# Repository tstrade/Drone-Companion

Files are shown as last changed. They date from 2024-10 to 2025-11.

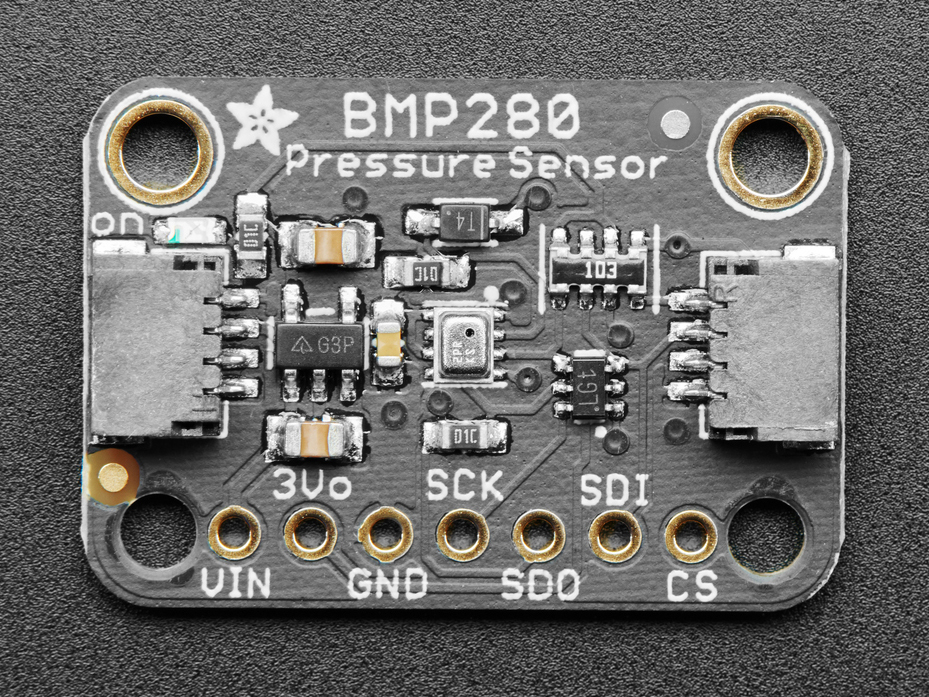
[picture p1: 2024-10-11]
Hardware/Pinouts/BMP280_Pinouts.jpg

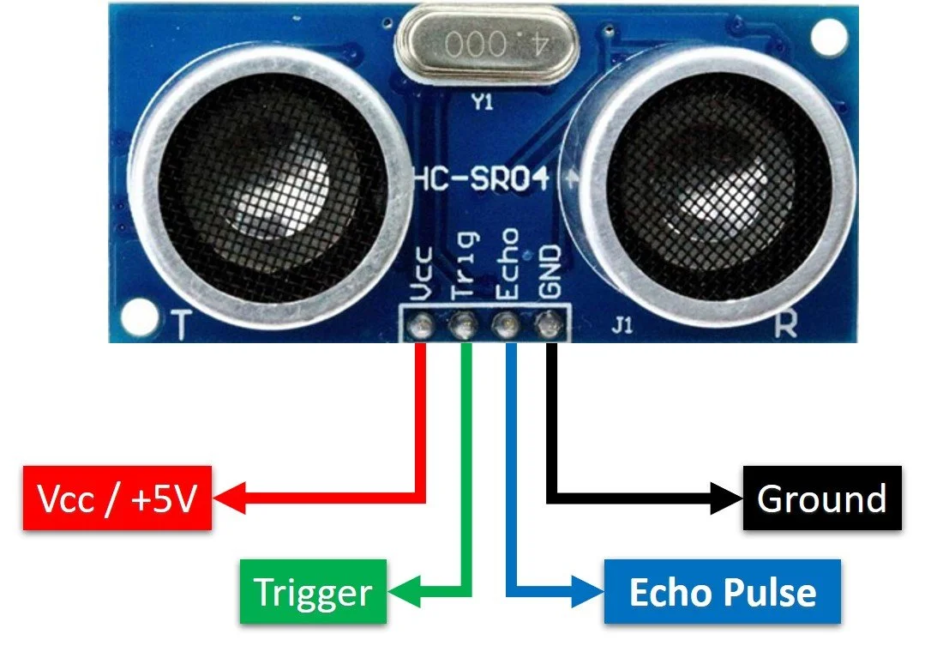
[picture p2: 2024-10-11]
Hardware/Pinouts/HC-SR04-Pinout.png

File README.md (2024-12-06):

# Drone-Companion
We will implement an assistive technology drone that will fly at a specific height above the user and detect, avoid, and alert when there are any obstacles. Obstacle can be constituted as anything that is large and can be ran into when walking around outside or in a building (i.e. walls, poles, tables, chairs, other people).  

The drone will follow the user while they walk around, maintaining that same distance every time the user moves while also monitoring the environment around the user to detect and avoid any other obstacles. It will specifically alert the user when there is an object in front of them that is getting closer and within some fixed proximity. 

***
# Repository Tour
- *Software*
    - Test code
    - Wokwi Simulations
    - Libraries downloaded to be used for the Drone Companion

- *Hardware*
    - Pinouts
    - Component markdown detailing inputs, outputs, and other specifications (as well as links to the manufacturers)
    - Datasheets
    - Designs used to 3D print the frame
    - Wokwi link to full wiring layout
 
- *Final Product*
    - Full prototype code / sketch
    - Full wiring layout
    - README.md detailing setup, use, and other important notes
 
- *Other*
    - Phase 1 Document: Project Proposal
    - Phase 2 Document: Prototype Progress Update

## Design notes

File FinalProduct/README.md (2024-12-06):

# Drone Companion - Prototype Setup and Functionality
***
## Setup:
1. Load Drone-Companion/FinalProduct/MasterCode/MasterCode.ino into the Arduino IDE
2. Connect Mini-B USB cable from laptop to Arduino Nano USB port and upload the code (nonstandard missing libraries can be found in the Drone-Companion repository)
3. Place the drone on a flat spot (ground, chair, table) and then upload the sketch
4. When the serial monitor instructs you to do so, plug the LiPo battery into the PDB
5. The motors will make a few short beeps and then one long beep to confirm the motors have been armed, then press the IR remote's ON button

***
## How to Use the Drone Companion:
- After the Drone Compion has been setup, it will initiate its takeoff protocol
  - To complete the takeoff protocol, the Drone Companion must be raised to a height 1 meter (approx. 3 feet) above its starting position
 
- After the takeoff protocol, the Drone Companion will assume its hover protocol
    - *Using the IR Remote*
        - The code received by the sensor starts from 0 (top left button), followed by 1, 2, 3; the next row will start on code 4, and so on
        - Using the codes:
            - **Code 1**: Hover protocol
            - **Code 2**: Takeoff protocol
            - **Code 3**: Landing protocol
            - **Other Codes**: Follow protocol
  
    - *Protocols*
        1. **Hover**: maintain a stable / constant height
        2. **Takeoff**: increase motor speed until 1 meter higher than the starting position
        3. **Land**: reduce drone speed over ~30 second period and then stop motors completely
        4. **Follow**: maintain distance from user by moving forwards or backwards
         
    - *Special Behavior*
        - **Hover** will not respond to user distance or obstacle proxomity
        - **Takeoff** can only occur when the drone is landed. If the takeoff protocol is activated while the drone is airborn, it will skip the takeoff sequence and default to the hover protocol
        - **Land** can only occur when the drone is airborn. If the landing protocol is activated while the drone is grounded, nothing will happen.
        - **Follow** will trigger the alarm if an obstacle comes too close to the drone and will only silence when the obstalce has moved away

***
## Notes:
- *LiPo Battery Life* - A fully charged 2200 mAh will allow the drone to run for approximately 6 to 10 minutes continuously before it needs to be recharged.
  
- *Calibration Sequences* - The Drone Companion should not be moved during setup, as it is taking time to calibrate the gyroscope. Additionally, the battery should not be plugged in nor the IR remote used sooner than indicated. This could cause an improper setup and remove any guarantee that the Drone Companion will function as expected.
    - You can find our version of a motor / ESC calibration sequence in "Drone-Companion/Software/Test Code"
 
- *Project Replication* - If you are building your own version, make sure to calibrate the motors to their specified minimum and maximum throttle in a sketch separate from the rest of the hardware. This usually only needs to happen once, but improper calibration or power malfunctions could reset this process. Make sure to follow the manufacturer's specifications. Additionally, PID control constants and complementary filters are NOT universal: these parameters are sensitive and should be tested extensively with the hardware you choose to use.
    - Research the hardware you are using. Understanding the units of the inputs and outputs is vital to proper testing. Additionally, some components may interfere with one another. For example, in this implementation, the IR sensor and buzzer use the same clock timer from the Arduino Nano - such a resource must be mutually exclusive
  
- *Testing Environment* - To avoid broken parts and/or injury, conduct initial testing without propellors. Use the Serial Monitor and visual/auditory queues to debug the motors's reaction to stimulus. When appropriate, choose a safe space to tie at least two of the motor props to heavy objects. It should be high enough off the ground that it will not crash in the event of an error, and tied in such a way that it cannot cut itself loose. Motors are powerful - make sure whatever you secure the drone with will not break from the force created by the drone. Finally, motors rotate over a hundred times per second, so propellors are essentially mini blades if you are not careful. Wear protective clothing and glasses while testing your drone.
 
***
## Final Remarks:
  In the timespan of ~3 months (as of Dec. 6, 2024), this drone has gone from an idea to a functional prototype. This prototype has not yet achieved full flight, due to complications such as the ones we have warned against above, as well as the limited resource that is time. Moving forward, there are two more major phases planned for the Drone Companion:
    - Phase 4 will include a remastering of the drone - a new frame, reorganized wiring, memory optimization, parameter refinement, and sensible testing. The goal of this phase is to have the drone successfully complete its takeoff, hover, and landing protocols.
    - Phase 5 will result in the final product, in which the drone will be able to enter its follow protocol and operate in a smooth, controlled manner.

  If you are seeking to build your own drone using an Arduino, or another microcontroller, it is important to not be discouraged. Integrating sensitive hardware requires careful and extensive testing, and lots (and we mean a lot) of failure. Many online forums, such as the Arduino Forum and Reddit, discourage programmers new to microcontrollers to not bother with a drone. Of course, there are also many useful tips out there on the internet - you just have to look around hard enough to find useful information that applies to you. Hopefully, this project will stand as a testimate to the power of determination and the pursuit of knowledge. 

Sincerely, 
Two undergraduates with a vision

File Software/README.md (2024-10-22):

This folder contains all necessary code, as well as psuedocode, pertaining to the operation
of the Drone Companion. Coding will be done in C and interfaced with an Arduino Nano. 

In the section below, each simulation serves as a basic example of how each of the hardware components will interact with our software individually and
how the software will communicate I/O data between different combinations of components. 

## Wokwi Simulations
### Individual Component Tests
- [Radar Sensor - HC-SR04](https://wokwi.com/projects/412025867077022721)
- [Gyroscope & Accelerometer - MPU6050](https://wokwi.com/projects/412048270927496193)
- [Altitude Sensor - BMP280](https://wokwi.com/projects/412088879688243201)
  
***
### Paired Component Tests
- [Radar Sensors, Accelerometer, Altitude Sensor, Buzzer](https://wokwi.com/projects/412369553864428545)

***

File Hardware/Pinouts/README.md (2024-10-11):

This directory contains Pinout Diagrams for all hardware components in the Drone Companion design.

Additional / More Descriptive info for the BMP280 pins are found [here](https://learn.adafruit.com/adafruit-bmp280-barometric-pressure-plus-temperature-sensor-breakout/pinouts)

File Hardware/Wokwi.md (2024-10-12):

[Here](https://wokwi.com/projects/411396309418092545) is the share link to the Drone Companion's hardware connections.

Current Items:
1. Arduino Nano
2. Radar sensor x2 (HC-SR04)
3. Altitude sensor (BMP280 - custom chipset)
4. 6-Axis Accelerometer & Gyro (MPU6050 - not final; stand-in component)
5. IR Receiver
6. Buzzer

Missing Items:
1. ESC x4
2. Brushless Motors x4
3. Power Control Board (possibly not necessary)
4. LiPO Battery (Ideally 45-60 min. flight time)
5. Medium breadboard

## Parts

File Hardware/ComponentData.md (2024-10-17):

# **Ultrasonic Sensor**
## Electric Parameters:

| Working Voltage | DC 5V |
| :---: | :---: |
| Working Current | 15mA |
| Working Frequency | 40Hz |
| Range | 0.03 - 13.12ft |
| Accuracy | 0.01ft|
| Measuring Angle | 15 degrees |
| Trigger Input Signal | 10us TTL Pulse |
| Echo Output Signal | Input TTL level signal and the range in proportion |

[Transistor-Transistor Logic (TTL)](https://meanwellpowersupplies.com/faq/what-is-a-ttl-signal/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,5V%20is%20a%20high%20state.)

- Basic Principles:
  1. Use I/O trigger for at least 10us logic HI
  2. Module automatically sends eigth 40kHz and detects whether there is a pulse signal back
  3. If there is a pulse signal back, through logic HI, time of logic HI I/O duration is from time sending ultrasonic to returning
  4. Appropriate test distance = (logic HI time * 1115ft/s)/2
       - where 1115ft/s is approx. the speed of sound (340m/s) in feet
    
- Wire Connections:
    - 5V supply
    - Trigger Pulse Input
    - Echo Pulse Output
    - 0V ground

The timing diagram and all information listed in this section can be found in the Ultrasonic Ranging Module HC-SR04 datasheet included in this repository. Any additional information may be found in the module's [Github Repository](https://github.com/sparkfun/HC-SR04_UltrasonicSensor)

## Dimensions:
- 45 x 20 x 15 millimeters
- 1.8 x 0.8 x 0.6 inches

## Input Data:
- To trigger, send a 10us TTL pulse to the module
  - TTL logic HI:  ~ 2.7 - 5.0V
  - TTL logic LO: ~ 0.0 - 0.4V
  - Note: This information might vary based on our component's capabilities. The TTL link above, as well as others, tend to be product-specific.
 
- Suggested to use a measurement cycle > 60ms to avoid I/O overlap

## Output Data:
- Sends a TTL pulse "with a range in proportion"
- The distance, in inches, of the object that is within the range/width of the sensor is defined as $$d = \frac{t_{o} - t_{i}}{148}$$

***
# **Altitude Sensor**
## Overview
- Barometric Pressure Accuracy: $\pm 1$ hPa
- Temperature Accuracy: $\pm 1.0^\circ$C
- Altimeter Accuracy: $\pm 1$ meter
- Low Altitude Noise: $0.25$ meters
- ! Can be used with 3.3V or 5V systems thanks to built-in voltage regulator

## Pinouts:
| Pins | Use |
| :---: | :---: |
| Vin | Power pin - use same power as logic level of microcontroller |
| 3Vo | 3.3V output from voltage regulator - can grab up to 100mA |
| GND | Common ground for power and logic |
| --------- | --------------------------------------------------------------------------------- |
| ***SPI*** | ***PROTOCOL PINS*** |
| SCK | SPI Clock Pin - input to chip |
| SDO | Serial Data Out / Microcontoller In Sensor Out pin - data sent from sensor to processor |
| SDI | Serial Data In / Microcontroller Out Sensor In pin - data sent from processor to sensor |
| CS | Chip Slect pin - drop to low to start SPI transaction; input to chip |
| --------- | --------------------------------------------------------------------------------- |
| ***I2C*** | ***PROTOCOL PINS*** |
| SCK (SCL) | I2C Clock Pin - connect to microcontroller's I2C clock line |
| SDI (SDA) | I2C Data Pin - connect to microcontroller's I2C data line |
| SDO | Leave unconnected |
| CS | Leave unconnected |

[BMP280 to Arduino Wiring-by-Protocol](https://learn.adafruit.com/adafruit-bmp280-barometric-pressure-plus-temperature-sensor-breakout/arduino-test)

## Input/Output Data:

Adafruit provides a library for the BMP280 that is available from the Arduino library manager, and can be installed from GitHub [here](https://github.com/adafruit/Adafruit_BMP280_Library/tree/master).

Additionally, the GitHub repository includes a few examples on how to interact with the BMP280 through an Arduino sketch. It is encouraged to review this documentation, but the examples can be summarized as follows: initialize sensor, call for a temperature and/or pressure reading using `getEvent()`, and store or print the value obtained by the sensor. 

What to look into during the coding subphase: 
- Different operating modes
- Oversampling values
- Standby timing
- Proper addressing for chosen protocol

In addition to the GitHub examples for library usage, the Adafruit provides a section on [how to use the library with the SPI protocol](https://learn.adafruit.com/adafruit-bmp280-barometric-pressure-plus-temperature-sensor-breakout/arduino-test). 

***
# **Flight Controllers**

| Specifications | Details Found [Here](https://www.rcelectricparts.com/40a-esc---classic-series.html) |
| :----: | :----: |
| Continuous | 40 A |
| Bursts | 60 A for 10 seconds |
| *UBEC | 5V/3A |
| LiPo Battery | 2 - 4 cells |
| **NiDc/NiMH | 5 - 12 cells |
| Dimensions | 71 x 35 x 10.5 mm |
| Weight | 48 g |
| Motor Type | Brushless |
| Max RMP - 2 Pole Motor | 240,000 RPM |
| Max RMP - 6 Pole Motor | 80,000 RPM |
| Max RMP - 12 Pole Motor | 40,000 RPM |

*Universal Battery Eliminator Circuit - converts high-voltage power to lower voltages
**Nickel-cadmium and Nickel-metal hydride are types of rechargeable batteries
  - NiCd has a short charge time and high discharge rate
  - NiMH is less toxic and holds more power

## Input/Output Data:
A complete guide to the GOUPRC 40A Brushless ESC can be found [here](https://www.rcelectricparts.com/classic-esc-user-guide.html).

- Connections
  - Battery: use pre-soldered XT60 plug
  - Motor: 3 wires (opposite the XT60 plug)
      - swap any two connections to reverse motor direction OR
      - program ESC to spin in reverse direction
  - Arduino: black ground, red 5V, white signal wires (next to XT60 plug)
 
- Input Signal
  - PWM Signal Frequency: 50 Hz
  - Zero Throttle: 1 ms pulse width
  - Full Throttle: 2 ms pulse width
  - *Note: PWM signal operates on a spectrum between these endpoints -> allows for incremental control*

*RC Electric Parts provides [this video](https://youtu.be/uOQk8SJso6Q) for Arduino usage*
 
## Procedures:
Calibration
  1. Put throttle in maximum position
  2. Plug in ESC
  3. Wait until ESC starts beeping
  4. While beeping, put throttle in minimum position
  5. Wait for confirmation beeps
  6. Unplug ESC
 
Start up
  1. Put throttle in minimum position
  2. Plug in ESC
  3. ESC will beep: 1x for each detecting cell + 1x if brake ON OR 2x if brake OFF
  4. ESC is ready

## Benefits:
- Smooth, programmable, and accurate linear throttle adjustment
- Supports high RPM motors
- Utilizes smaller MOSFETs to minimize weight
- Minimal heat dissipation
- Pre-soldered with 3.5 mm Bullet Plugs and an XT60 Plug
- Reduces electromagnetic interference signal input
- Beeps during start up to confirm the number of battery cells

## Built-In Safety Features:
- Start-up Protection: will stop powering motor if it detects motor is unable to spin after start up
- Safe Start Protection: will not power the motor on start up unless throttle is in minimum throttle position to prevent dangerous accidental start ups
- Overheat Protection: output power reduces to 40% when over $100^\circ$C ($212^\circ$F)
- Lost Signal Protection: when signal is lost the ESC cutes the motor's power to prevent a runaway object
- Low Voltage Protection: if battery voltage drops below programmed threshold, will shut off or reduce throttle depending on programmed settings

*Note: Need to investigate how some of these criteria are met to avoid false-alarms / self-inflicted bugs*

***
# **Accelerometer / Gyroscope**

| Specifications | Details Found [Here](https://www.haoyuelectronics.com/Attachment/GY-521/mpu6050.pdf) |
| :----: | :----: |
| Main Chip | MPU-6050 |
| Power Supply | 3.3-5 V |
| VDD | 2.375-3.46 V |
| VLOGIC | $1.71 \pm 5%$ OR VDD |
| Operaitng Current | 3.9 mA |
| Communication Mode | I2C Protocol (using Wire Arduino Library) |
| Chip Built-in | 16 bit A/D converter, 16 bit data output |
| Gyroscopic Range | $\pm$ 250, 500, 1000, 2000 degrees/sec |
| Gyroscope Operating Current | 3.6 mA |
| Gyroscope Standby Current | 5 $\micro$A |
| Gyroscope Start up Time | 30 ms |
| Acceleration Range | $\pm$ 2, 4, 8, 16g |
| Accelerometer Operating Current | 500 $\mu$A |
| Accelerometer Low Power Current at 1.25 Hz | 10 $\micro$A |
| Accelerometer Low Power Current at 5 Hz | 20 $\micro$A |
| Accelerometer Low Power Current at 20 Hz | 60 $\micro$A |
| Accelerometer Low Power Current at 40 Hz | 110 $\micro$A |

| Gyro/Accel Axes | 3 (X, Y, Z) |

Important Notes:
- I2C Operating Frequency ranges from 100 to 400 kHz
- IC2 Address is either `AD0 = 0` ($1101000$) or `AD0 = 1` ($1101001$)

## Pinout Summary:
- Pin 8: VLOGIC
- Pin 9: AD0
- Pin 23: SCL
- Pin 24: SDA

## Input Data:
- High Level Input Voltage $V_{IH} = 0.7 \times$ VLOGIC
- Low Level Input Voltage $V_{IL} = 0.3 \times$ VLOGIC
- Gyro sensitivity set by `FS_SEL = 0, 1, 2, or 3` (corresponding values defined in table above)
- Accel sensitivity set by `AFS_SEL = 0, 1, 2, or 3` (corresponding values defined in table above)

## Output Data:
- High Level Output Voltage $V_{OH} = 0.9 \times$ VLOGIC (assuming a load resistor of $R_L = 1M\Omega$
- Low Level Output Voltage $V_{OL} = 0.1 \times$ VLOGIC (assuming a load resistor of $R_L = 1M\Omega$
- Data rate of 8000 Hz (Gyro), 1000 Hz (Accel)
- 1024 byte FIFO buffer
  - Reduces power consumption by allowing host processor to read data in bursts and go into low-power mode as sensor collects more data
- Digital output temperature sensor
- Possibility for gesture recognition??? (page 11 of manual linked above)

***
# **Power Distribution Board**

***
# **Motors**

| Specifications | Details Found [Here](https://speedyfpv.com/products/720-brushed-motor-set-4pcs-7x20mm-coreless-motor-1mm-shaft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) |
| :----: | :----: |
| Operating Voltage | 3.7-4.2 V |
| Operating Current | 80-100 mA |
| Speed | 45,000 RPM |
| Motor Diameter | 7 mm |
| Motor Length | 20 mm |
| Propeller Shaft Diameter | 1 mm |
| Propeller Shaft Length | 5 mm |
| Propeller Length | 55 mm |
| Overall Weight | 3g |

***
# **Buzzer**

***
# **IR Transmitter/Receiver**

| Output | active at low level (0.2 V) |
| Power supply | 4.5 V ~ 5.5 V |
| Power consumption | 0.6 mA |
| Wavelength | 940 nm |
| BPF center frequency | 38 kHz |
| Operating temperature | -10°C ~ +60°C |
| Signal range | max. 10 m |
| Dimensions | 7.3 x 7.6 x 5.2 mm |
| Weight | 0.68 g |

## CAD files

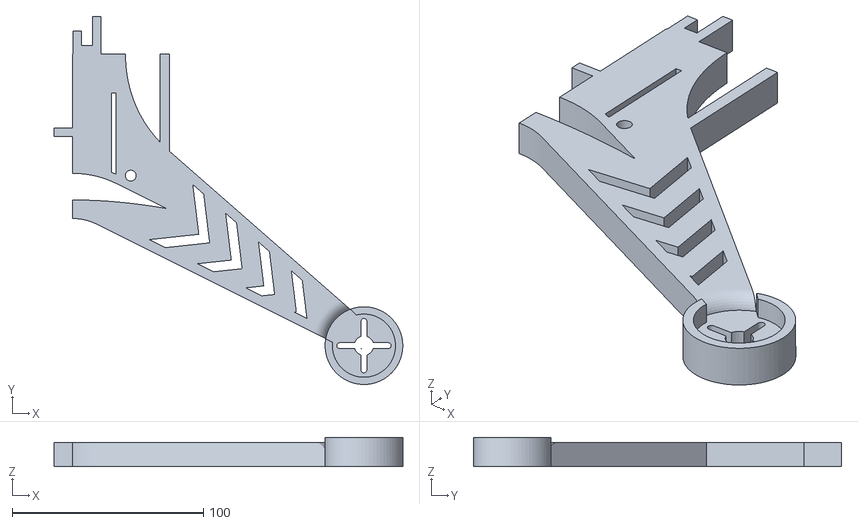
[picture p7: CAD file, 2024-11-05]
Hardware/INDIVIDUAL_MALE_DRONE_PART.stl
182.2 x 192.4 x 15.2

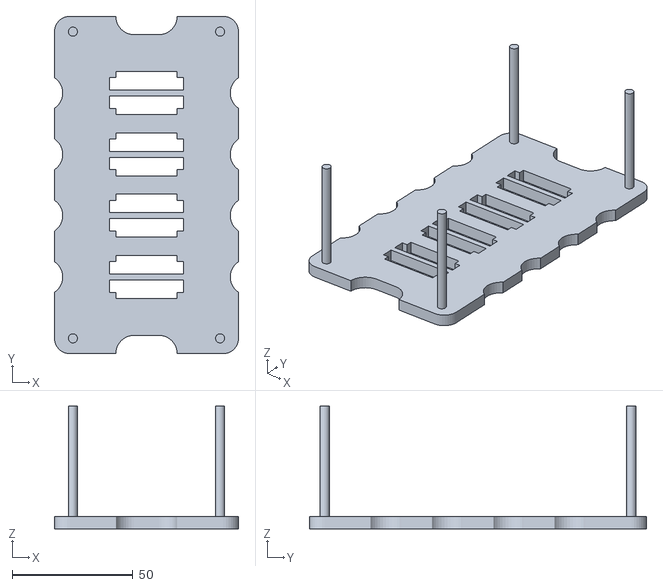
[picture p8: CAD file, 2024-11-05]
Hardware/DRONE_FRAME_CAGE.stl
76.2 x 139.7 x 50.8

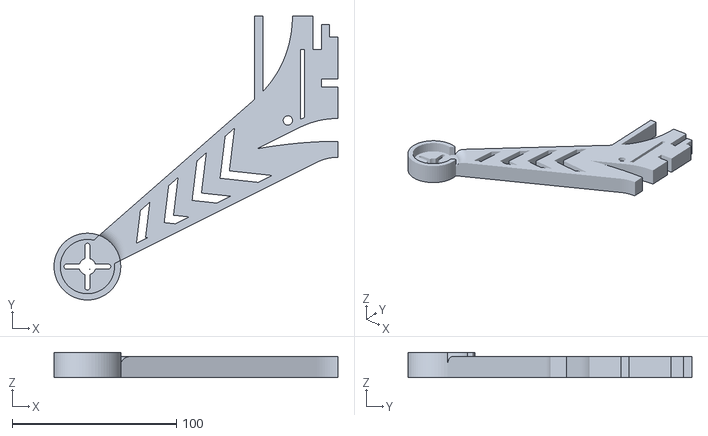
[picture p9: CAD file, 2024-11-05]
Hardware/INDIVIDUAL_FEMALE_DRONE_WING.stl
172.7 x 172.7 x 15.2

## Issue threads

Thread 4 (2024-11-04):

Radar Functionality

tstrade, 2024-11-04:
Arduino code for radar 1 (keeping distance from user) and radar 2 (detecting oncoming objects)
  ---> Motor & Buzzer response to radar information can be left as comments generally describing what the reaction will be

Closed 2024-11-12.

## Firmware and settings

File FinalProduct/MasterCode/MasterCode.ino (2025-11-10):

#include <Wire.h>
#include <Servo.h>
#include <MPU6050.h>
#include <SPI.h>
#include <Adafruit_Sensor.h>
#include <Adafruit_BMP280.h> 
#include <IRremote.h>
#include "pitches.h"

// Servo motors (ESCs)
Servo FL, FR, BL, BR;
int speeds[4];

// Motor speed parameters
const int minMotorSpeed = 1000, maxMotorSpeed = 2000;
int targetMotorSpeed = 1700;
int IN_FLIGHT = 0;

// Radar pins
#define trigBack 4
#define echoBack 2
#define trigFront 14
#define echoFront 15

// Radars
Servo frontRadar, backRadar;
const float preferredDistance = 60.0; // Preferred distance in cm
const float distanceTolerance = 10.0; // Tolerance of +/- 10cm

// Buzzer
#define BUZZER_PIN 8
const int alarm = NOTE_FS5;

// MPU6050 instace
MPU6050 mpu;

// Gyro and accelerometer error offsets
typedef struct {
  float X, Y, Z;
} Error;

Error gyroError = {0, 0, 0}, accelError = {0, 0, 0};
float previousPitch = 0.0, integralPitch = 0.0, PitchPID;
float previousRoll = 0.0, integralRoll = 0.0, RollPID;
float pitch = 0.0, roll = 0.0, yaw = 0.0;

// BMP280 instance
Adafruit_BMP280 bmp(10);
float altitudeThreshold = 5.0;
const float stdAirPressure = 1013.25;

// IR receiver
IRrecv receiverIR(7);
volatile int IRCode = 0;

// Time tracking
unsigned long previousTime;

// Debugging count
int DEBUG;

// Function prototypes
void applySpeeds(int speeds[]); // Motors
void calibrateSensors(int samples); // MPU6050
void computeAngles(float elapsedTime); // MPU6050
void PIDControl(float elapsedTime); // Motors & MPU6050
void adjustMotors(); // Motors
int softClamp(int value, int min, int max); // Motors
void checkIRCode(); // IR receiver
int calculateDistance(int trigPin, int echoPin); // Radars
void moveForwards(float updatedSpeed);
void moveBackwards(float updatedSpeed);
void follow();
void takeOff();
void land();
void checkObstacle();
void debugOutput(); 

void setup() {
  Serial.begin(115200);
  Wire.begin();

  // Initialize BMP280
  bmp.begin();
  Serial.println(F("BMP280 initialized."));

  //setup radars output and input reading
  pinMode(trigFront, OUTPUT);
  pinMode(echoFront, INPUT);
  digitalWrite(trigFront, LOW);
  Serial.println(F("Front radar initialized."));

  pinMode(trigBack, OUTPUT);
  pinMode(echoBack, INPUT);
  digitalWrite(trigBack, LOW);
  Serial.println(F("Back radar initialized."));

  // Setup IR sensor
  receiverIR.enableIRIn();
  Serial.println(F("IR Receiver initialized."));

  /// Initialize and calibrate the MPU6050
  Serial.println(F("Initializing MPU6050"));
  while (!mpu.begin(MPU6050_SCALE_250DPS, MPU6050_RANGE_2G)) {
    Serial.println(F("Failed to find MPU6050 chip, checking wiring!"));
    delay(500);
  }
  // Built-in calibration (not great)
  mpu.calibrateGyro(1000);
  mpu.setThreshold(3);
  // Manual calibration to find offsets
  calibrateSensors(500);
  Serial.println(F("MPU6050 initialized and calibrated."));

  //setup buzzer pin output reading
  pinMode(BUZZER_PIN, OUTPUT);
  Serial.println(F("Buzzer initialized."));
  
  for (int i = 0; i < 4; i++) {
    speeds[i] = minMotorSpeed;
  }

  // Attach and arm ESCs
  FL.attach(3); 
  FR.attach(9);
  BL.attach(5);
  BR.attach(6);

  applySpeeds(speeds);
  Serial.println(F("Plug in the ESCs - wait for confirmation beeps"));
  while (IRCode != 2) { checkIRCode(); }
  Serial.println(F("Servo motors successfuly armed -- System Ready!\n"));

  delay(1000);
  previousTime = micros();
}

void loop() {
  checkIRCode();
  unsigned long currentTime = micros();
  float elapsedTime;
  // Sampling rate = 2000 Hz
  if (currentTime - previousTime >= 500) {
    elapsedTime = (currentTime - previousTime) / 1e6; // Convert to seconds
    previousTime = currentTime;
    switch(IRCode) {
      case 1: // Just hover
        Serial.println(F("Hovering..."));
        // Compute angles and apply PID
        computeAngles(elapsedTime);
        PIDControl(elapsedTime);
        // Adjust motors
        adjustMotors();
        break;
      case 2: // Takeoff sequence
        if (IN_FLIGHT == 0) { takeOff(); }
        Serial.println(F("TAKEOFF SUCCESSFUL!"));
        IRCode = 1;
        break;
      case 3: // Landing sequence
        if (IN_FLIGHT) { land(); Serial.println(F("LANDING SUCCESSFUL!")); }
        break;
      default: // Follow the user
        Serial.println(F("Following..."));
        follow();
        // Compute angles and apply PID
        computeAngles(elapsedTime);
        PIDControl(elapsedTime);
        // Adjust motors
        adjustMotors();
        checkObstacle();
        break;
    }
  }
}


/******************************************************/
void 
applySpeeds(int speeds[]) {
  FL.writeMicroseconds(speeds[0]);
  FR.writeMicroseconds(speeds[1]);
  BL.writeMicroseconds(speeds[2]);
  BR.writeMicroseconds(speeds[3]);
}


void 
calibrateSensors(int samples) {
  Vector gyro, accel;

  for (int i = 0; i < samples; i++) {
    gyro = mpu.readNormalizeGyro();
    accel = mpu.readNormalizeAccel();
    
    gyroError.X += gyro.XAxis;
    gyroError.Y += gyro.YAxis;
    gyroError.Z += gyro.ZAxis;
    
    accelError.X += accel.XAxis;
    accelError.Y += accel.YAxis;
    accelError.Z += accel.ZAxis;  

    delay(1);
  }
  gyroError.X /= samples, gyroError.Y /= samples, gyroError.Z /= samples;
  accelError.X /= samples, accelError.Y /= samples, accelError.Z /= samples;

  Serial.println(F("Calibration complete. Verifying error..."));
}


void 
computeAngles(float elapsedTime) {
  // Read and adjust gyroscope / accelerometer
  Vector gyro = mpu.readNormalizeGyro();
  gyro.XAxis -= gyroError.X, gyro.YAxis -= gyroError.Y, gyro.ZAxis -= gyroError.Z;
  Serial.print("DEBUG #");
  Serial.print(++DEBUG);
  Serial.print(F(" X: ")); Serial.print(gyro.XAxis); Serial.print(", ");
  Serial.print(F("Y: ")); Serial.print(gyro.YAxis); Serial.print(", ");
  Serial.print(F("Z: ")); Serial.print(gyro.ZAxis); Serial.print(", ");

  Vector accel = mpu.readNormalizeAccel();
  accel.XAxis -= accelError.X, accel.YAxis -= accelError.Y, accel.ZAxis -= accelError.Z;

  // Calculate pitch and roll from gyroscope
  float gyroPitch = pitch + gyro.YAxis * elapsedTime;
  float gyroRoll = roll + gyro.XAxis * elapsedTime; 

  float accRoll = (atan2(accel.YAxis, sqrt(pow(accel.XAxis, 2) + pow(accel.ZAxis, 2))) * 180 / PI) ;
  float accPitch = (atan2(-1.0 * accel.XAxis, sqrt(pow(accel.YAxis, 2) + pow(accel.ZAxis, 2))) * 180 / PI); 

  // Apply complementary filter of alpha = 98%
  pitch = (pitch + 0.98 * gyroPitch + (0.02) * accPitch) / 2.0;
  roll = (roll + 0.98 * gyroRoll + (0.02) * accRoll) / 2.0;

  yaw += gyro.ZAxis * elapsedTime;
}


void 
PIDControl(float elapsedTime) {
  // P = proportional gain -> magnitude of response to error
  // I = integral control -> how fast error is removed (increase ki = decrease response time)
  // D = derivate control -> how far in the future to predict rate of change
  float kp = 1.01, ki = 0.6, kd = 0.00003; // PID constants

  // u(t) = kp * e(t) + ki * integral_0^t e(x)dx + kd * d/dx * e(t)
  PitchPID = kp * pitch + ki * (integralPitch += pitch * elapsedTime) + kd * (pitch - previousPitch) / elapsedTime;
  previousPitch = pitch;
  RollPID = kp * roll + ki * (integralRoll += pitch * elapsedTime) + kd * (pitch - previousPitch) / elapsedTime;
  previousRoll = roll;
}


// Alternative to the abruptness of constrain()
int 
softClamp(int value, int min, int max) {
  if (value < min) return min + (value - min) / 6;
  if (value > max) return max + (value - max) / 6;
  return value;
}


void 
adjustMotors() {
  // Scale corrections to keep adjustments moderate
  float scale = 0.25;

  // positive pitch -> back side needs to increase speed
  // positive roll -> right side needs to increase speed
  int targetSpeeds[4] = {
    targetMotorSpeed + (-PitchPID - RollPID) * scale, // Front left
    targetMotorSpeed + (-PitchPID + RollPID) * scale, // Front right
    targetMotorSpeed + (PitchPID - RollPID) * scale, // Back left
    targetMotorSpeed + (PitchPID + RollPID) * scale // Back right
  };

  // Calculate motor speed adjustments w/ soft clamping to smoothly enforce bounds
  for (int i = 0; i < 4; i++) {
    speeds[i] = softClamp(0.75 * speeds[i] + 0.25 * targetSpeeds[i], targetMotorSpeed - 30, targetMotorSpeed + 30);
  }

  // Write speeds to motors 
  applySpeeds(speeds);

  debugOutput();
}


void 
checkIRCode() {
  if (receiverIR.decode()) { 
    IRCode = receiverIR.decodedIRData.command; 
    delayMicroseconds(10);
    receiverIR.resume();
  }
}


int 
calculateDistance(int trigPin, int echoPin){
  digitalWrite(trigPin, LOW);
  delayMicroseconds(2);
  digitalWrite(trigPin, HIGH);
  delayMicroseconds(10);
  digitalWrite(trigPin, LOW);
  return (pulseIn(echoPin, HIGH) * 0.034/2);
}


void 
moveForwards(float updatedSpeed) {
  speeds[2] = updatedSpeed, speeds[3] = updatedSpeed;
  applySpeeds(speeds);
}


void 
moveBackwards(float updatedSpeed) {
  speeds[0] = updatedSpeed, speeds[1] = updatedSpeed;
  applySpeeds(speeds);
}


void 
follow() {
  backRadar.write(trigBack);
  delayMicroseconds(500);
  float userDistance = calculateDistance(trigBack, echoBack);
  float distanceDifference, motorSpeed;
  
  // Move towards user gradually 
  if (userDistance > (preferredDistance + distanceTolerance)) {
    distanceDifference = userDistance - preferredDistance;
    motorSpeed = map(distanceDifference, 0, preferredDistance, targetMotorSpeed - 50, targetMotorSpeed + 50);
    moveBackwards(motorSpeed);
  }

  // Move away from user gradually
  if (userDistance < (preferredDistance - distanceTolerance)) {
    distanceDifference = preferredDistance - userDistance;
    motorSpeed = map(distanceDifference, 0, preferredDistance, targetMotorSpeed - 50, targetMotorSpeed + 50);  // Gradually increase speed
    moveForwards(motorSpeed);
  }
}


void 
takeOff() {
  Serial.println(F("Taking off!"));
  float tempTarget = targetMotorSpeed;
  targetMotorSpeed = minMotorSpeed;

  float droneAltitude = bmp.readAltitude(stdAirPressure);
  float targetAltitude = droneAltitude + 1.0; // meters

  while (droneAltitude < targetAltitude) {
    droneAltitude = bmp.readAltitude(stdAirPressure);
    float alpha = map(targetAltitude - droneAltitude, -0.5, 1.5, 0, 1);
    unsigned long currentTime = micros();
    float elapsedTime;
    // Sampling rate = 2000 Hz
    if (currentTime - previousTime >= 500) {
      elapsedTime = (currentTime - previousTime) / 1e6; // Convert to seconds
      previousTime = currentTime;
      
      // Slowly increase speed
      targetMotorSpeed = alpha * targetMotorSpeed + (1 - alpha) * tempTarget;

      // Compute angles and apply PID
      computeAngles(elapsedTime);
      PIDControl(elapsedTime);

      // Adjust motors
      adjustMotors();  
      delayMicroseconds(100);  // Adjust delay for smoother takeoff
    }
  }
  targetMotorSpeed = tempTarget;
  IN_FLIGHT = 1;
}


void 
land() {
  int tempTarget = targetMotorSpeed;
  Serial.print(F("Landing..."));
  while (targetMotorSpeed > minMotorSpeed) {
    unsigned long currentTime = micros();
    // Sampling rate = 2000 Hz
    if (currentTime - previousTime >= 500) {
      float elapsedTime = (currentTime - previousTime) / 1e6; // Convert to seconds
      previousTime = currentTime;

      // Compute angles and apply PID
      computeAngles(elapsedTime);
      PIDControl(elapsedTime);

      // Adjust motors
      adjustMotors(); 
      targetMotorSpeed -= 3;
      delay(100);
    }
  }
  int off[4] = {0,0,0,0};
  applySpeeds(off);
  IN_FLIGHT = 0;
  targetMotorSpeed = tempTarget;
}


void 
checkObstacle() {
  frontRadar.write(trigFront);
  delayMicroseconds(500);
  int obstacleDist = calculateDistance(trigFront, echoFront);
  if (obstacleDist < 11.11) {
    receiverIR.stopTimer();
    tone(BUZZER_PIN, alarm);
    delay(250);
    noTone(BUZZER_PIN);
    receiverIR.restartTimer();
    delayMicroseconds(100);
  }
}


void 
debugOutput() {
  // Log values for debugging
  Serial.print(F("Pitch: ")); 
  Serial.print(pitch); Serial.print(F(","));
  Serial.print(F("   Roll: ")); 
  Serial.print(roll); Serial.print(F(","));
  Serial.print(F("   Yaw: ")); 
  Serial.print(yaw); Serial.print(F(","));
  
  Serial.print(F("   FL: ")); 
  Serial.print(speeds[0]); Serial.print(F(","));
  Serial.print(F("   FR: ")); 
  Serial.print(speeds[1]); Serial.print(F(","));
  Serial.print(F("   BL: ")); 
  Serial.print(speeds[2]); Serial.print(F(","));
  Serial.print(F("   BR: "));
  Serial.println(speeds[3]);
}

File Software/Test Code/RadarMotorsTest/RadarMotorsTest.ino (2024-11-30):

#include <Servo.h>
#include <IRremote.h>
#include "pitches.h"

// buzzer pin and tone
#define BUZZER_PIN 8
const int alert_tone = NOTE_FS5;

// radar pins
#define trigFront 14
#define echoFront 15
#define trigBack 4
#define echoBack 2

// Inititialize radars and motors in servo objects
Servo frontRadar, backRadar;
Servo motorBackRight;
Servo motorFrontLeft;
Servo motorBackLeft;
Servo motorFrontRight;

int obstacleFlag = 0;
float prevSpeed = 0;
float motorSpeed, userDist;

//Initialize IR reciever in an IRrecv object
IRrecv recieverIR(7);
int IRCode  = 0;
int results;

int minMotorSpeed = 90;  // Minimum throttle
int maxMotorSpeed = 180;  // Maximum throttle

void armESC() {
    // Set high throttle
    delay(2000);
    motorBackRight.write(maxMotorSpeed);
    motorFrontLeft.write(maxMotorSpeed);
    motorBackLeft.write(maxMotorSpeed);
    motorFrontRight.write(maxMotorSpeed);
    delay(5000);
    // Set low throttle
    motorBackRight.write(minMotorSpeed);
    motorFrontLeft.write(minMotorSpeed);
    motorBackLeft.write(minMotorSpeed);
    motorFrontRight.write(minMotorSpeed);
    delay(3000); 
    // Arm ESCs
    motorBackRight.write(45);
    motorFrontLeft.write(45);
    motorBackLeft.write(45);
    motorFrontRight.write(45);
    delay(1500);
}

void setup() {
  Serial.begin(9600);
  // Attach ESCs
  motorFrontLeft.attach(3);  // Pin 3 for front left motor
  motorFrontRight.attach(9); // Pin 5 for front right motor
  motorBackLeft.attach(5);   // Pin 6 for back left motor
  motorBackRight.attach(6);  // Pin 9 for back right motor

  // Calibration and Arming sequence
  armESC();
  /*
  motorBackRight.write(minMotorSpeed);
  motorFrontLeft.write(minMotorSpeed);
  motorBackLeft.write(minMotorSpeed);
  motorFrontRight.write(minMotorSpeed);
  Serial.println("Plug in ESCs now - wait for confirmation beep");
  while (!Serial.available()) {}
  Serial.read();
  delay(1000);
  */
  // Setup IR sensor
  recieverIR.enableIRIn();

  // Setup radars
  pinMode(trigFront, OUTPUT);
  pinMode(echoFront, INPUT);
  pinMode(trigBack, OUTPUT);
  pinMode(echoBack, INPUT);

  // Setup buzzer
  pinMode(BUZZER_PIN, OUTPUT);
}

int checkIRCode(){
  if (recieverIR.decode()) { 
    IRCode = recieverIR.decodedIRData.command; 
    delay(10);
    recieverIR.resume();
  }
  return IRCode;
}

float calculateDistance(int trig, int echo, int flag) {
  digitalWrite(trig, LOW);
  delayMicroseconds(2);
  digitalWrite(trig, HIGH);
  delayMicroseconds(10);
  digitalWrite(trig, LOW);
  float dist = pulseIn(echo, HIGH) * 0.034/2;
  if (trig == trigFront && flag && dist < 15.0) {
    tone(BUZZER_PIN, alert_tone);
    return dist;
  } else {
    return dist;
  }
}

void loop() {
  // Receive input from remote
  checkIRCode();
  Serial.println(IRCode);

  // Check user distance to adjust motors
  backRadar.write(trigBack);
  userDist = calculateDistance(trigBack, echoBack, 0);
  Serial.print("User dist (cm) is: ");
  Serial.println(userDist);

  // Setup reference speed
  if (!prevSpeed) {
      prevSpeed = map(userDist, 0, 300, 50, 180);
  }

  // Detect obstacle distance to alert buzzer
  frontRadar.write(trigFront);
  int obstacleDist = calculateDistance(trigFront, echoFront, obstacleFlag);
  Serial.print("Obstacle distance is: ");
  Serial.println(obstacleDist);
  if (obstacleFlag) { delay(250); }
  noTone(BUZZER_PIN); 
  
  switch (IRCode) {
    case 3: // Stop motors
      obstacleFlag = 0;
      motorBackRight.write(0);
      motorFrontLeft.write(0);
      motorBackLeft.write(0);
      motorFrontRight.write(0);
      break;
    case 2: // Medium-high speed
      obstacleFlag = 0;
      motorBackRight.write(100);
      motorFrontLeft.write(100);
      motorBackLeft.write(100);
      motorFrontRight.write(100);
      break;
    case 0: // Speed & buzzer based on radars
      obstacleFlag = 1;
      motorSpeed = (2 * map(userDist, 0, 300, 50, 180) + 3 * prevSpeed) / 5;
      prevSpeed = motorSpeed;
      Serial.print("New speed is: ");
      Serial.println(motorSpeed);
      motorBackRight.write(motorSpeed);
      motorFrontLeft.write(motorSpeed);
      motorBackLeft.write(motorSpeed);
      motorFrontRight.write(motorSpeed);
      break;
    default: // Idle speed
      obstacleFlag = 0;
      motorBackRight.write(50);
      motorFrontLeft.write(50);
      motorBackLeft.write(50);
      motorFrontRight.write(50);
      break;
  }
}

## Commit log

2024-10-09 Create ComponentPacketData.md
    This file will serve as a general guide as to how each component expects to receive and transmit data, as well as any necessary Arduino methods/libraries, possible scheduling issues/precedences, etc.
2024-10-10 Ultrasonic sensor information filled out/updated in Packet Data file
2024-10-17 Update ComponentData.md
    All information for the ESCs and the brushless motors has been included (as well as any supporting links / documentation)
2024-10-17 Update ComponentData.md
    Most gyro/accel data has been input - still need to finish the Input/Output section
2024-10-17 Update ComponentData.md - added IR sensor
2024-10-18 Update README.md
    Added Radar, Accelerometer, and Altitude sensor coding examples from Wokwi simulations
2024-10-30 Notes on ESC library
    I found an Arduino library for ESCs which is based on the servo library. Here are my notes on the library and possible functions we can use. can be updated as research continues.
2024-10-31 Init Gyro/Accel Test - Not Working I think
    [GyroAccelTest_WIP.ino]
2024-11-05 3d CAD models of drone frame
    [DRONE_FRAME_CAGE.stl, INDIVIDUAL_FEMALE_DRONE_WING.stl, INDIVIDUAL_MALE_DRONE_PART.stl]
2024-11-05 esc calib
2024-11-06 ESC library code
    Calibrates, Arms, and runs each motor.
2024-11-07 Radar Functionality V2
    Added setup code for radars plus function for calculating distance. Still need to test radars to find preferred distance. additionally have motor behavior but not specific values yet. otherwise the c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
2024-11-07 Added both functional and manual calibration and arming
    Currently motors only work when you run only one of them. have not tested manual code yet but i expect it to run similarly. When a motor beeps repeatedly forever, idk what that means. However, when a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
2024-11-07 Update ESC_Calibration.ino parallel calibration
2024-11-07 Create ESC_TakeOff.ino motor test without initial calibration
2024-11-07 Update ESC_TakeOff.ino detach doesn't take any arguments
    [ESC_TakeOff.ino]
2024-11-07 Update ESC_TakeOff.ino - fixed timing
    [ESC_TakeOff.ino]
2024-11-10 Altitude sensor - Accuracy +- 1m
2024-11-14 Take off, stabilization, landing
2024-11-14 Added setup variables and functions for IR, Buzzer, and Radar
    [MasterCode.ino]
2024-11-14 Added void follow(float motorSpeed)
    Added a follow function that only responds to the radar facing the user.
2024-11-21 IR Startup
    This should work. I believe this is how we should go about polling the code from the IR remote. The only problem faced here is how to extract the integer out of the code. I assume it is quite easy but I am unable to troubleshoot it at the moment.
    [IR_Start_Test.ino]
2024-11-21 Follow and Detect Test
    This handles both radar sensors so that the motors follow the radar that faces the user when there is not an obstacle and then stops and starts buzzing when the radar facing an obstacle detects and obstacle. wow is this a great description
    [Follow_Detect_with_Buzzer.ino]
2024-11-27 trying to get the radars to change the motors
2024-11-27 Motors now respond to IR remote and radar distance
2024-11-27 Motors respond to everything, but IR sensor stops working after the buzzer goes off
    [RadarMotorsTest.ino]
2024-11-30 Trying to get the gyroscope to stabilize the drone
    [ESC_Calibration.ino, GyroAccelTest_WIP.ino, RadarMotorsTest.ino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]
2024-11-30 Fixed IR remote issue - shares a timer with the buzzer
    [IR_Buzzer_Fix.ino]
2024-12-01 adjusting filter and other calculations
2024-12-01 desperately trying to stabilize this thing
    [Stabalize_Test.ino]
2024-12-02 its so over - one of the motor mounts broke during testing
    [Stabalize_Test.ino]
2024-12-02 Finished up master code
    - Stabilization with PID controls & complementary filters
    - Refactored
    - All hardware functionality is included (IR sensor, buzzer, radars, BMP, MPU, ESCs)
    [MasterCode.ino]
2024-12-02 full wiring + moved master code
2024-12-05 editing some prints and fixed landing error
    [Stabalize_Test.ino]
2025-11-10 Fix formatting in setup and loop functions
    [BMP280_WIP.ino]
